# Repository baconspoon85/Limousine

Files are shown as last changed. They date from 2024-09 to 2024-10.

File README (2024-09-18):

Limousine is a drop in PCB replacement for Keychron Q9. This layout is intended to support a 30% layout plus right-side numpad.
-Hotswap MX switch sockets
-2u or split backspace
-Right side numpad with 2u or split 0.
-Traditional row stagger or alpha stagger layout options
-Multiple bottom row layout options including 7u, 10u (with 7u stabilizer mounts), 6u, split 2.25u/2.75u, and a solder only split 3u option
-Two EC11 push button encoders positions, both iterchangeable with hotswap MX switches
NOTE: The split 3u spacebar option is included to accomodate layouts with dedicated left hand mods. It requires soldered switches for the spacebar positions and removal of the hotswap socket for the 2.75u right spacebar position.

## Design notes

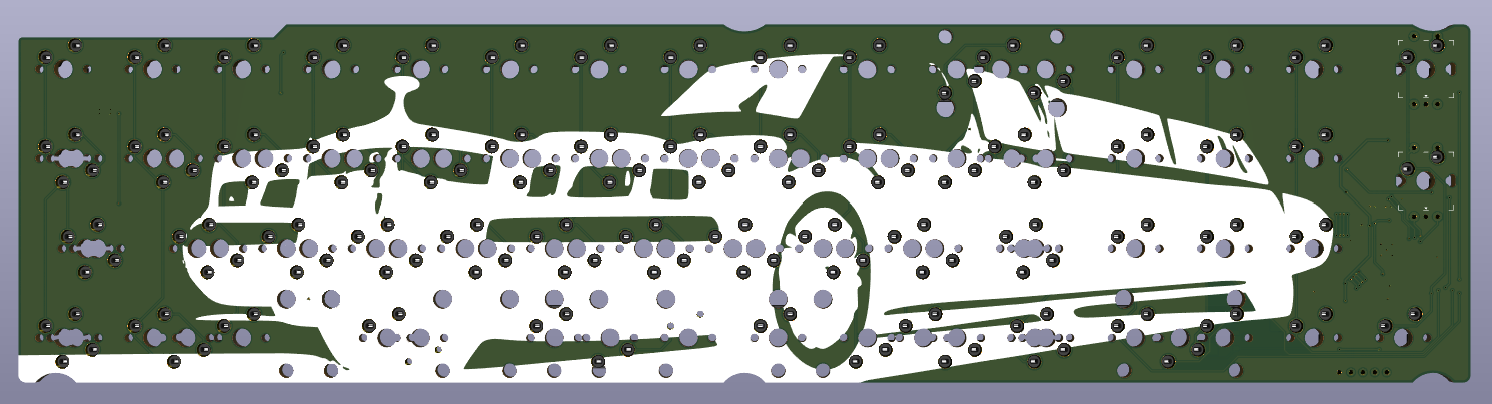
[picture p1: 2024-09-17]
limousine-pcb/pcb-render.png

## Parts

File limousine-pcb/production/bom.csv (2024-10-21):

Designator | Footprint | Quantity | Value | LCSC Part #
BOOT1, RST1 | SW_SPST_TL3342 | 2 | SW_Push | C318884
C1, C11, C2, C3, C6 | 402 | 5 | 1u | C52923
C10, C12 | 402 | 2 | 22p | C1555
C13, C14, C15, C16, C4, C7, C8, C9 | 402 | 8 | 100n | C1525
C5 | 603 | 1 | 10u | C19702
D1, D10, D11, D12, D13, D14, D15, D16, D17, D18, D19, D2, D20, D21, D22, D23, D24, D25, D26, D27, D28, D29, D3, D30, D31, D32, D33, D35, D36, D37, D38, D39, D4, D40, D41, D42, D43, D44, D45, D46, D47, D48, D49, D5, D50, D52, D54, D55, D56, D57, D58, D59, D6, D60, D61, D62, D63, D7, D8, D9 | D_SOD-123_xomm | 60 | D_Small | C81598
J1 | JST_SH_BM07B-SRSS-TB_1x07-1MP_P1.00mm_Vertical | 1 | Conn_01x07 | C160393
MX1, MX16, MX2, MX3, MX32, MX53, MX54, MX55 | SW_MX_HS_S_CPG151101S11_1u | 8 | MX_SW_HS | C5156480
MX10, MX11, MX12, MX13, MX14, MX15, MX17, MX18, MX19, MX20, MX21, MX22, MX23, MX24, MX25, MX26, MX27, MX28, MX29, MX30, MX31, MX34, MX35, MX36, MX37, MX38, MX39, MX4, MX40, MX41, MX42, MX45, MX46, MX47, MX48, MX5, MX50, MX52, MX56, MX57, MX59, MX6, MX61, MX62, MX63, MX64, MX65, MX66, MX68, MX7, MX70, MX71, MX72, MX73, MX74, MX75, MX76, MX77, MX78, MX8, MX81, MX82, MX83, MX84, MX85, MX86, MX87, MX88, MX89, MX9 | SW_MX_HS_CPG151101S11_1u | 70 | MX_SW_HS | C5156480
MX33, MX44 | SW_MX_HS_CPG151101S11_1.5u | 2 | MX_SW_HS | C5156480
MX49, MX51, MX58, MX60, MX69, MX90 | SW_MX_HS_CPG151101S11_1.25u | 6 | MX_SW_HS | C5156480
MX79, MX80 | SW_MX_HS_CPG151101S11_1.75u | 2 | MX_SW_HS | C5156480
MXS1, MXS2 | SW_MX_1u | 2 | MX_SW_HS | C5156480
R3, R4, R5 | 402 | 3 | 5.1k | C25905
R6, R9 | 402 | 2 | 1k | C11702
R7, R8 | 402 | 2 | 27 | C25100
U1 | SOT-23-3 | 1 | XC6206PxxxMR | C2897477
U2 | SOT-23-6-routable | 1 | SRV05-4 | C2836319
U3 | QFN-56-1EP_7x7mm_P0.4mm_EP3.2x3.2mm | 1 | RP2040 | C2040
U4 | SOIC-8_5.23x5.23mm_P1.27mm | 1 | W25Q128JVS | C97521
Y1 | Crystal_SMD_3225-4Pin_3.2x2.5mm | 1 | Crystal_GND24 | C403945

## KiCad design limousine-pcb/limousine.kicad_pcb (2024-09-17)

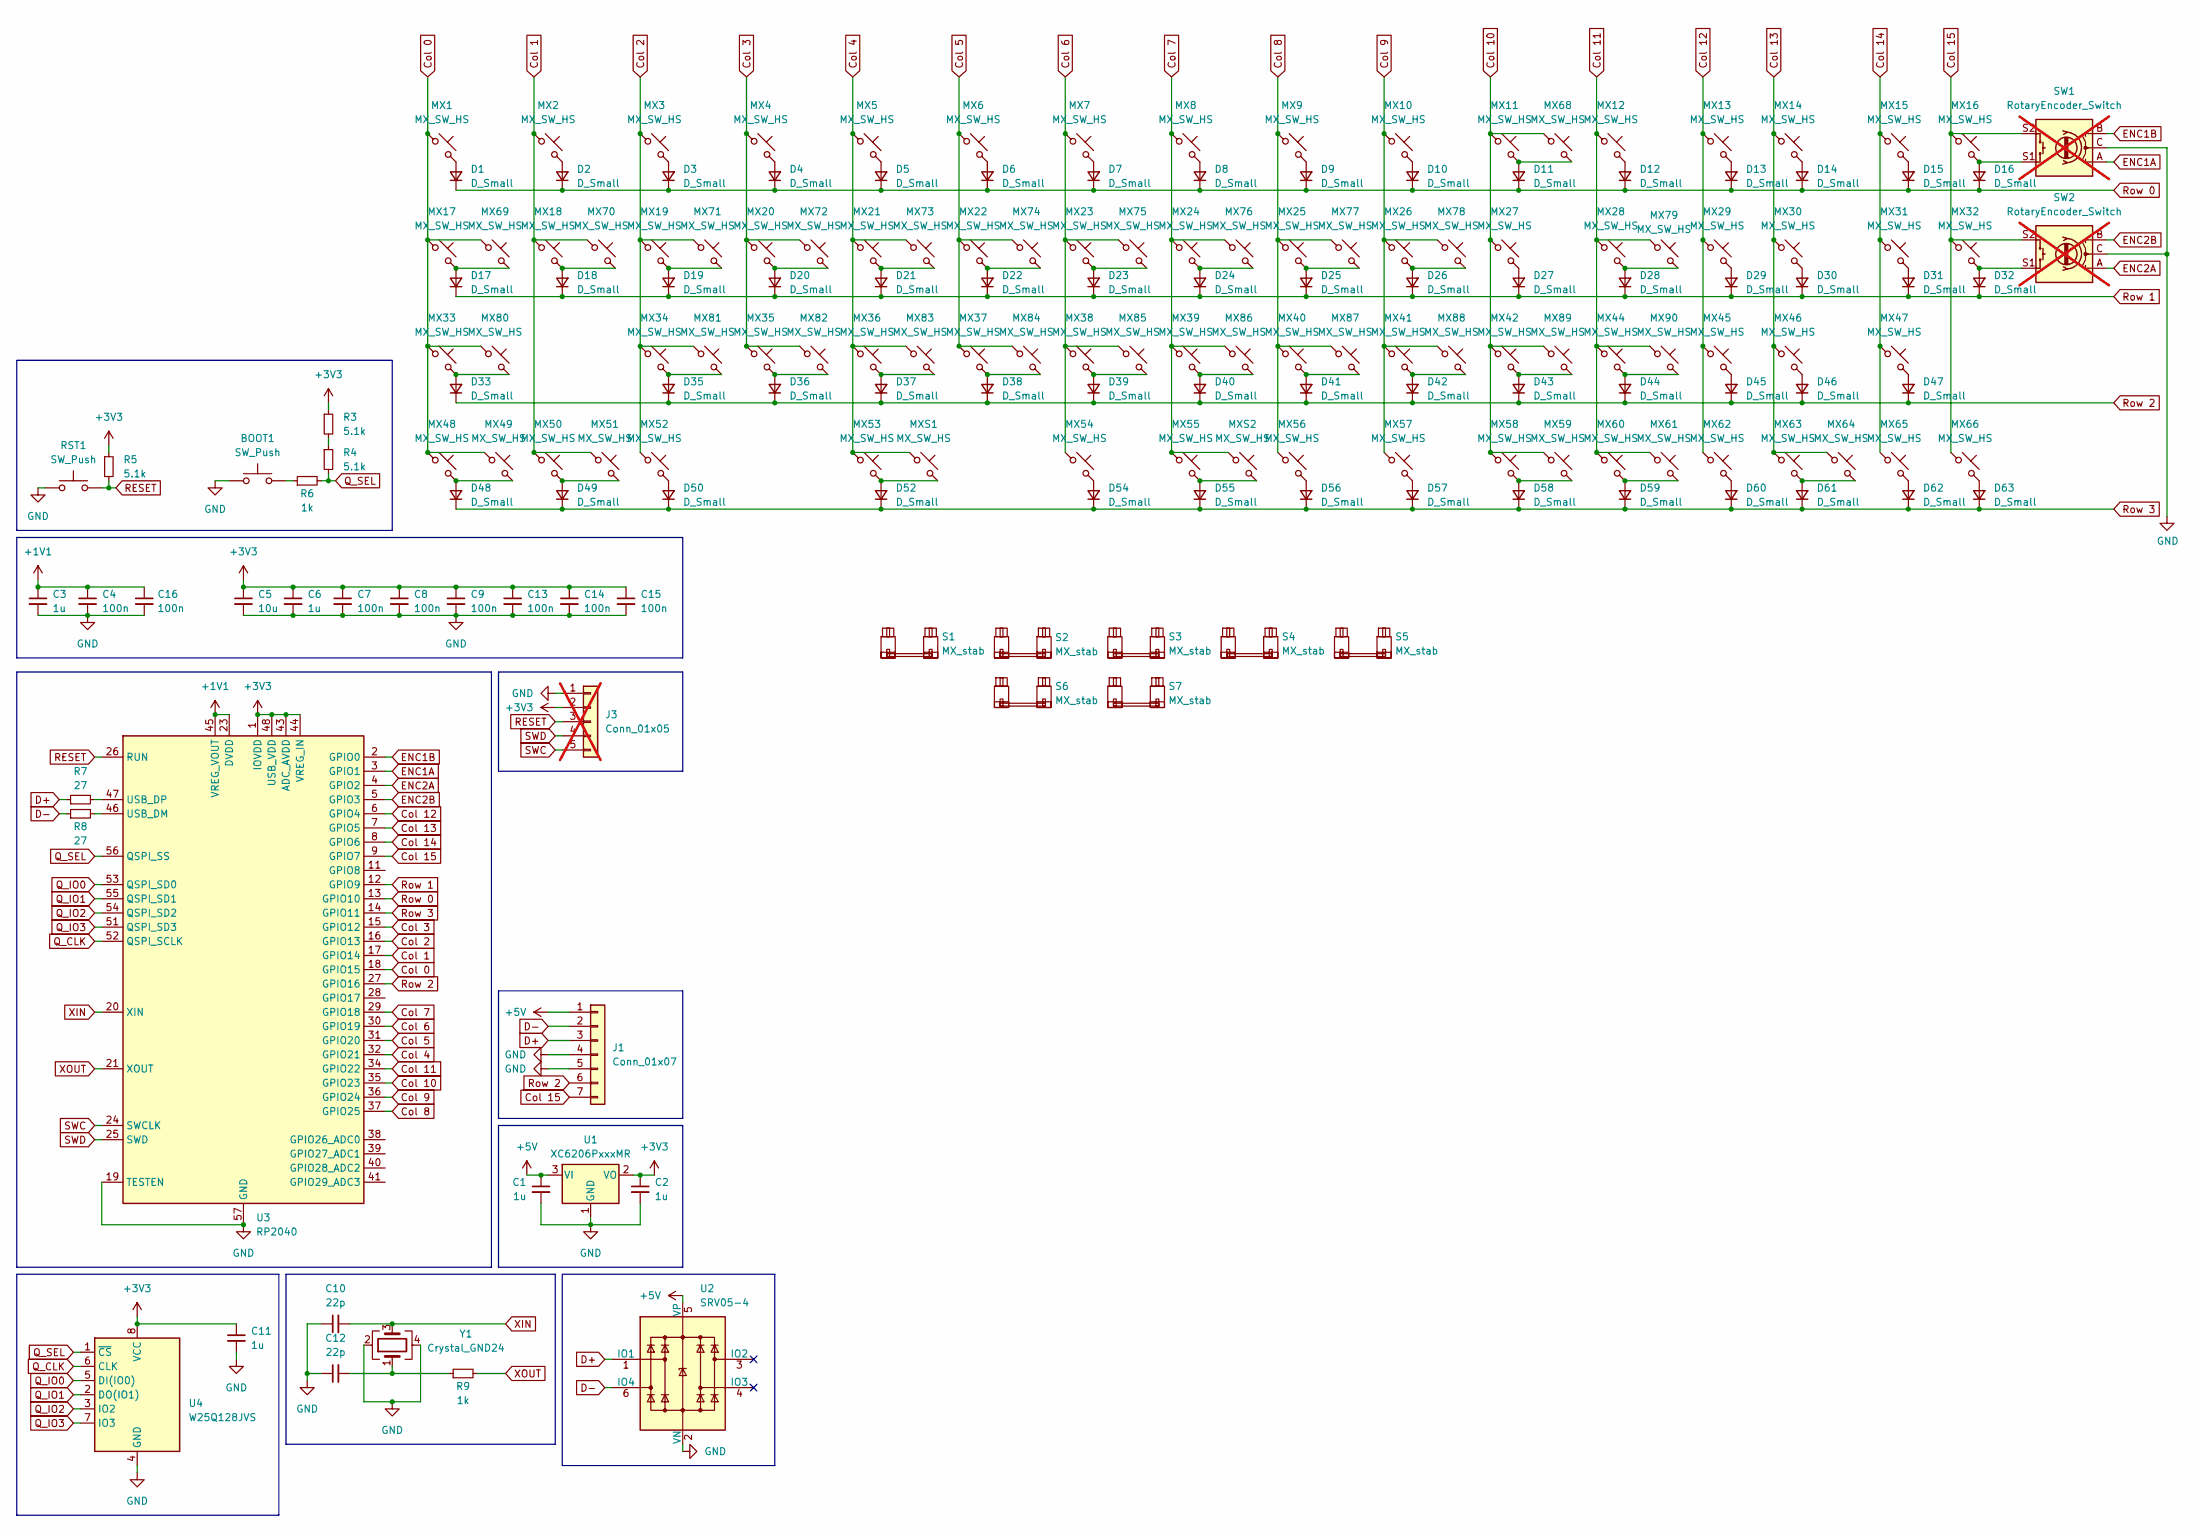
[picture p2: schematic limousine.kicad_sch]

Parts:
BOOT1: SW_Push; SW_SPST_TL3342
C1, C2, C3, C6, C11: 1u; C_0402_1005Metric
C4, C7, C8, C9, C13, C14, C15, C16: 100n; C_0402_1005Metric
C5: 10u; C_0603_1608Metric
C10, C12: 22p; C_0402_1005Metric
D1, D2, D3, D4, D5, D6, D7, D8, D9, D10, D11, D12, D13, D14, D15, D16, D17, D18, D19, D20, D21, D22, D23, D24, D25, D26, D27, D28, D29, D30, D31, D32, D33, D35, D36, D37, D38, D39, D40, D41, D42, D43, D44, D45, D46, D47, D48, D49, D50, D52, D54, D55, D56, D57, D58, D59, D60, D61, D62, D63: D_Small; D_SOD-123_xomm
J1: Conn_01x07; JST_SH_BM07B-SRSS-TB_1x07-1MP_P1.00mm_Vertical
J3: Conn_01x05; PinHeader_1x05_P2.54mm_Vertical; not fitted
MX1, MX2, MX3, MX16, MX32: MX_SW_HS; SW_MX_HS_S_CPG151101S11_1u
MX4, MX5, MX6, MX7, MX8, MX9, MX10, MX11, MX12, MX13, MX14, MX15, MX17, MX18, MX19, MX20, MX21, MX22, MX23, MX24, MX25, MX26, MX27, MX28, MX29, MX30, MX31, MX34, MX35, MX36, MX37, MX38, MX39, MX40, MX41, MX42, MX45, MX46, MX47, MX48, MX50, MX52, MX53, MX54, MX55, MX56, MX57, MX59, MX61, MX62, MX63, MX64, MX65, MX66, MX68, MX70, MX71, MX72, MX73, MX74, MX75, MX76, MX77, MX78, MX81, MX82, MX83, MX84, MX85, MX86, MX87, MX88, MX89: MX_SW_HS; SW_MX_HS_CPG151101S11_1u
MX33, MX44: MX_SW_HS; SW_MX_HS_CPG151101S11_1.5u
MX49, MX51, MX58, MX60, MX69, MX90: MX_SW_HS; SW_MX_HS_CPG151101S11_1.25u
MX79, MX80: MX_SW_HS; SW_MX_HS_CPG151101S11_1.75u
MXS1, MXS2: MX_SW_HS; SW_MX_1u
R3, R4, R5: 5.1k; R_0402_1005Metric
R6, R9: 1k; R_0402_1005Metric
R7, R8: 27; R_0402_1005Metric
RST1: SW_Push; SW_SPST_TL3342
S1: MX_stab; STAB_MX_2.25u
S2: MX_stab; STAB_MX_7u
S3: MX_stab; STAB_MX_2.75u
S4, S5: MX_stab; STAB_MX_2u
S6, S7: MX_stab; STAB_MX_3u
SW1, SW2: RotaryEncoder_Switch; ROT_Alps_EC11E-Switch; not fitted
U1: XC6206PxxxMR; SOT-23-3
U2: SRV05-4; SOT-23-6-routable
U3: RP2040; QFN-56-1EP_7x7mm_P0.4mm_EP3.2x3.2mm
U4: W25Q128JVS; SOIC-8_5.23x5.23mm_P1.27mm
Y1: Crystal_GND24; Crystal_SMD_3225-4Pin_3.2x2.5mm

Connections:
+1V1: C3.1, C4.1, C16.1, U3.23 (DVDD), U3.45 (VREG_VOUT), U3.50 (DVDD)
+3V3: C2.1, C5.1, C6.1, C7.1, C8.1, C9.1, C11.1, C13.1, C14.1, C15.1, J3.2, R3.1, R5.1, U1.2 (VO), U3.1 (IOVDD), U3.10 (IOVDD), U3.22 (IOVDD), U3.33 (IOVDD), U3.42 (IOVDD), U3.43 (ADC_AVDD), U3.44 (VREG_IN), U3.48 (USB_VDD), U3.49 (IOVDD), U4.8 (VCC)
+5V: C1.1, J1.1, U1.3 (VI), U2.5 (VP)
Col 0: MX1.1, MX17.1, MX33.1, MX48.1, MX49.1, MX69.1, MX80.1, U3.18 (GPIO15)
Col 1: MX2.1, MX18.1, MX50.1, MX51.1, MX70.1, U3.17 (GPIO14)
Col 2: MX3.1, MX19.1, MX34.1, MX52.1, MX71.1, MX81.1, U3.16 (GPIO13)
Col 3: MX4.1, MX20.1, MX35.1, MX72.1, MX82.1, U3.15 (GPIO12)
Col 4: MX5.1, MX21.1, MX36.1, MX53.1, MX73.1, MX83.1, MXS1.1, U3.32 (GPIO21)
Col 5: MX6.1, MX22.1, MX37.1, MX74.1, MX84.1, U3.31 (GPIO20)
Col 6: MX7.1, MX23.1, MX38.1, MX54.1, MX75.1, MX85.1, U3.30 (GPIO19)
Col 7: MX8.1, MX24.1, MX39.1, MX55.1, MX76.1, MX86.1, MXS2.1, U3.29 (GPIO18)
Col 8: MX9.1, MX25.1, MX40.1, MX56.1, MX77.1, MX87.1, U3.37 (GPIO25)
Col 9: MX10.1, MX26.1, MX41.1, MX57.1, MX78.1, MX88.1, U3.36 (GPIO24)
Col 10: MX11.1, MX27.1, MX42.1, MX58.1, MX59.1, MX68.1, MX89.1, U3.35 (GPIO23)
Col 11: MX12.1, MX28.1, MX44.1, MX60.1, MX61.1, MX79.1, MX90.1, U3.34 (GPIO22)
Col 12: MX13.1, MX29.1, MX45.1, MX62.1, U3.6 (GPIO4)
Col 13: MX14.1, MX30.1, MX46.1, MX63.1, MX64.1, U3.7 (GPIO5)
Col 14: MX15.1, MX31.1, MX47.1, MX65.1, U3.8 (GPIO6)
Col 15: J1.7, MX16.1, MX32.1, MX66.1, SW1.S2, SW2.S2, U3.9 (GPIO7)
D+: J1.3, R7.1, U2.1 (IO1)
D-: J1.2, R8.1, U2.6 (IO4)
ENC1A: SW1.A, U3.3 (GPIO1)
ENC1B: SW1.B, U3.2 (GPIO0)
ENC2A: SW2.A, U3.4 (GPIO2)
ENC2B: SW2.B, U3.5 (GPIO3)
GND: BOOT1.1, C1.2, C2.2, C3.2, C4.2, C5.2, C6.2, C7.2, C8.2, C9.2, C10.1, C11.2, C12.1, C13.2, C14.2, C15.2, C16.2, J1.4, J1.5, J3.1, RST1.1, SW1.C, SW2.C, U1.1 (GND), U2.2 (VN), U3.19 (TESTEN), U3.57 (GND), U4.4 (GND), Y1.2, Y1.4
unnamed: BOOT1.2, R6.1
unnamed: C12.2, R9.1, Y1.1
unnamed: D1.2 (A), MX1.2
unnamed: D2.2 (A), MX2.2
unnamed: D3.2 (A), MX3.2
unnamed: D4.2 (A), MX4.2
unnamed: D5.2 (A), MX5.2
unnamed: D6.2 (A), MX6.2
unnamed: D7.2 (A), MX7.2
unnamed: D8.2 (A), MX8.2
unnamed: D9.2 (A), MX9.2
unnamed: D10.2 (A), MX10.2
unnamed: D11.2 (A), MX11.2, MX68.2
unnamed: D12.2 (A), MX12.2
unnamed: D13.2 (A), MX13.2
unnamed: D14.2 (A), MX14.2
unnamed: D15.2 (A), MX15.2
unnamed: D16.2 (A), MX16.2, SW1.S1
unnamed: D17.2 (A), MX17.2, MX69.2
unnamed: D18.2 (A), MX18.2, MX70.2
unnamed: D19.2 (A), MX19.2, MX71.2
unnamed: D20.2 (A), MX20.2, MX72.2
unnamed: D21.2 (A), MX21.2, MX73.2
unnamed: D22.2 (A), MX22.2, MX74.2
unnamed: D23.2 (A), MX23.2, MX75.2
unnamed: D24.2 (A), MX24.2, MX76.2
unnamed: D25.2 (A), MX25.2, MX77.2
unnamed: D26.2 (A), MX26.2, MX78.2
unnamed: D27.2 (A), MX27.2
unnamed: D28.2 (A), MX28.2, MX79.2
unnamed: D29.2 (A), MX29.2
unnamed: D30.2 (A), MX30.2
unnamed: D31.2 (A), MX31.2
unnamed: D32.2 (A), MX32.2, SW2.S1
unnamed: D33.2 (A), MX33.2, MX80.2
unnamed: D35.2 (A), MX34.2, MX81.2
unnamed: D36.2 (A), MX35.2, MX82.2
unnamed: D37.2 (A), MX36.2, MX83.2
unnamed: D38.2 (A), MX37.2, MX84.2
unnamed: D39.2 (A), MX38.2, MX85.2
unnamed: D40.2 (A), MX39.2, MX86.2
unnamed: D41.2 (A), MX40.2, MX87.2
unnamed: D42.2 (A), MX41.2, MX88.2
unnamed: D43.2 (A), MX42.2, MX89.2
unnamed: D44.2 (A), MX44.2, MX90.2
unnamed: D45.2 (A), MX45.2
unnamed: D46.2 (A), MX46.2
unnamed: D47.2 (A), MX47.2
unnamed: D48.2 (A), MX48.2, MX49.2
unnamed: D49.2 (A), MX50.2, MX51.2
unnamed: D50.2 (A), MX52.2
unnamed: D52.2 (A), MX53.2, MXS1.2
unnamed: D54.2 (A), MX54.2
unnamed: D55.2 (A), MX55.2, MXS2.2
unnamed: D56.2 (A), MX56.2
unnamed: D57.2 (A), MX57.2
unnamed: D58.2 (A), MX58.2, MX59.2
unnamed: D59.2 (A), MX60.2, MX61.2
unnamed: D60.2 (A), MX62.2
unnamed: D61.2 (A), MX63.2, MX64.2
unnamed: D62.2 (A), MX65.2
unnamed: D63.2 (A), MX66.2
unnamed: R3.2, R4.1
unnamed: R8.2, U3.46 (USB_DM)
unnamed: R7.2, U3.47 (USB_DP)
Q_CLK: U3.52 (QSPI_SCLK), U4.6 (CLK)
Q_IO0: U3.53 (QSPI_SD0), U4.5 (DI(IO0))
Q_IO1: U3.55 (QSPI_SD1), U4.2 (DO(IO1))
Q_IO2: U3.54 (QSPI_SD2), U4.3 (IO2)
Q_IO3: U3.51 (QSPI_SD3), U4.7 (IO3)
Q_SEL: R4.2, R6.2, U3.56 (QSPI_SS), U4.1 (~CS)
RESET: J3.3, R5.2, RST1.2, U3.26 (RUN)
Row 0: D1.1 (K), D2.1 (K), D3.1 (K), D4.1 (K), D5.1 (K), D6.1 (K), D7.1 (K), D8.1 (K), D9.1 (K), D10.1 (K), D11.1 (K), D12.1 (K), D13.1 (K), D14.1 (K), D15.1 (K), D16.1 (K), U3.13 (GPIO10)
Row 1: D17.1 (K), D18.1 (K), D19.1 (K), D20.1 (K), D21.1 (K), D22.1 (K), D23.1 (K), D24.1 (K), D25.1 (K), D26.1 (K), D27.1 (K), D28.1 (K), D29.1 (K), D30.1 (K), D31.1 (K), D32.1 (K), U3.12 (GPIO9)
Row 2: D33.1 (K), D35.1 (K), D36.1 (K), D37.1 (K), D38.1 (K), D39.1 (K), D40.1 (K), D41.1 (K), D42.1 (K), D43.1 (K), D44.1 (K), D45.1 (K), D46.1 (K), D47.1 (K), J1.6, U3.27 (GPIO16)
Row 3: D48.1 (K), D49.1 (K), D50.1 (K), D52.1 (K), D54.1 (K), D55.1 (K), D56.1 (K), D57.1 (K), D58.1 (K), D59.1 (K), D60.1 (K), D61.1 (K), D62.1 (K), D63.1 (K), U3.14 (GPIO11)
SWC: J3.5, U3.24 (SWCLK)
SWD: J3.4, U3.25 (SWD)
XIN: C10.2, U3.20 (XIN), Y1.3
XOUT: R9.2, U3.21 (XOUT)

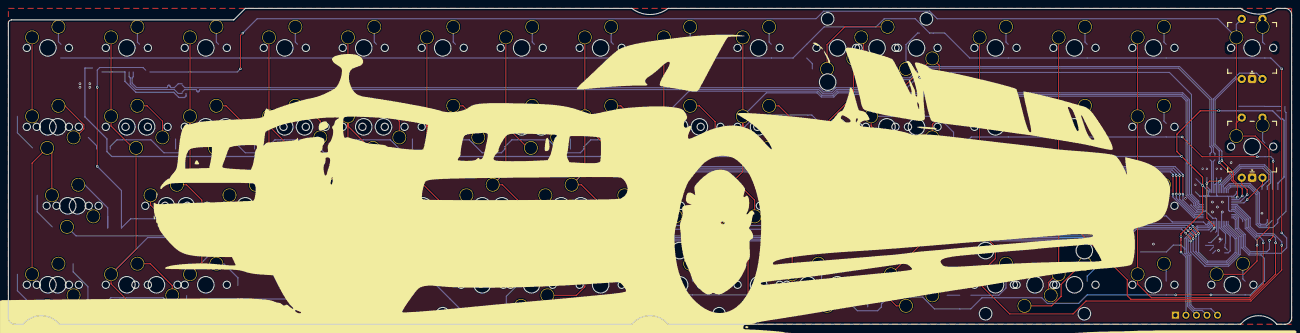
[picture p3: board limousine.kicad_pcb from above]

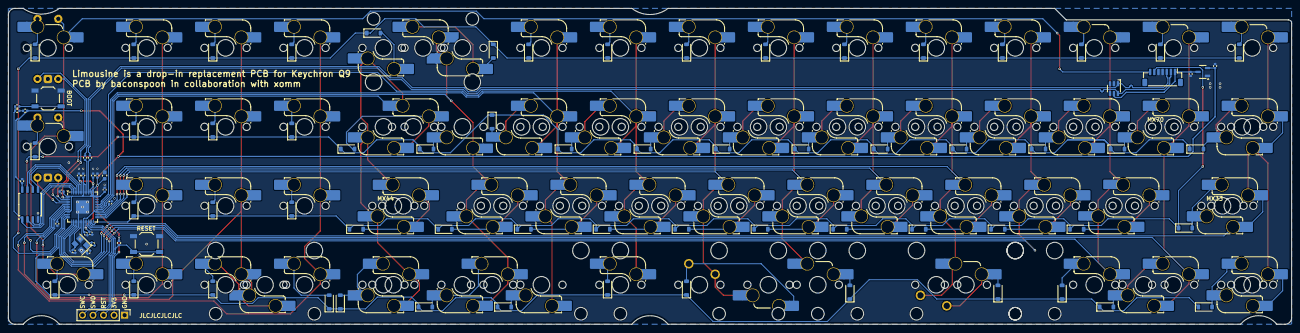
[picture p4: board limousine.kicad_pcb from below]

Board: 2 copper layers, 309.6 x 76.2 mm, 191 parts (180 on the bottom side), 106 nets.

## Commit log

2024-09-17 add pcb render
2024-09-18 added plate files
    [Limousine-B_Cu.gbr, Limousine-B_Mask.gbr, Limousine-B_Paste.gbr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]
2024-10-21 update production files used in v1 run
    [bom.csv, designators.csv, limousine-plate.kicad_pcb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]
